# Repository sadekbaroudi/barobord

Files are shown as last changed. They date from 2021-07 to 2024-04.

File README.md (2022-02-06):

# Pronunciation

Bar-oh-board

# Support me!

I have spent a lot of time and money designing prototypes, testing, developing, etc. Any contributions would be greatly appreciated!

If you don't want to, or can't afford to support me, please send me a message to let me know you've built one, along with pictures. Also, feel free to submit a pull request with pictures into this repository. I'd be happy to showcase your build.

Reddit: /u/sadekbaroudi
Discord: sadekbaroudi#1258



# Overview

This is a split monoblock keyboard with 40 keys, a 25% typing angle, and other goodies. Feel free to use for personal use, but any selling or reselling of this is prohibited without explicit consent.

There are three versions of this board. I have personally fabricated and tested the mx and the choc versions. I have not tested the byo-mcu version, but it's the same wiring as the mx version (and much simpler). It should work fine.

See the build guide, descriptions of the three versions, and BOM for all three here:
https://github.com/sadekbaroudi/barobord/blob/master/BUILDGUIDE.md

# Do you want to test the layout?

Print the file below on a sheet of paper. Test it out!

[Layout tester](layout-tester.pdf)

# Firmware

barobord supports [vial](https://get.vial.today/)! Download it, build and flash the firmware, and vial will allow you to configure it. If you don't want to learn how to flash firmware, I have prebuilt some that you can find here:
[Prepared firmware](https://github.com/sadekbaroudi/barobord/tree/master/firmware)

If you want to build the firmware yourself, you can access it here for the integrated atmega32u4 version:
[Barobord QMK firmware](https://github.com/sadekbaroudi/vial-qmk/tree/vial/keyboards/fingerpunch/barobord)

Or here for the byo-mcu version:
[Barobord byo-mcu QMK firmware](https://github.com/sadekbaroudi/vial-qmk/tree/vial/keyboards/fingerpunch/barobord_byomcu)

# Images

## v1-mx

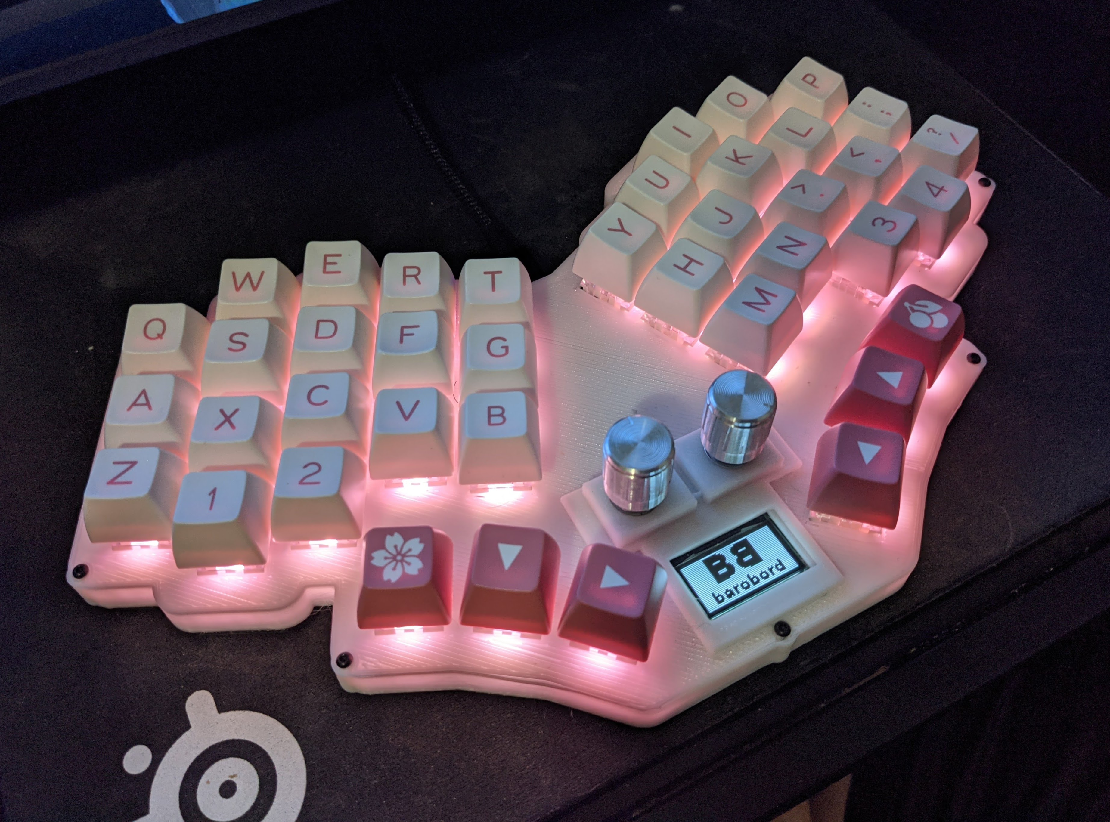
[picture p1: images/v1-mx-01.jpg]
v1mx01


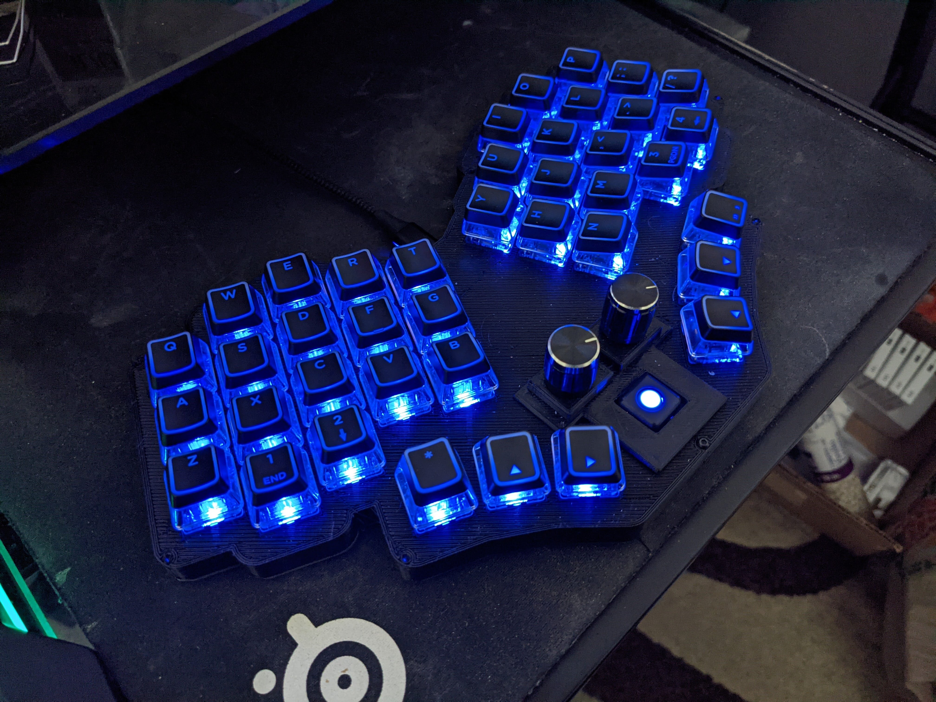
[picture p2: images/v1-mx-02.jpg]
v1mx02


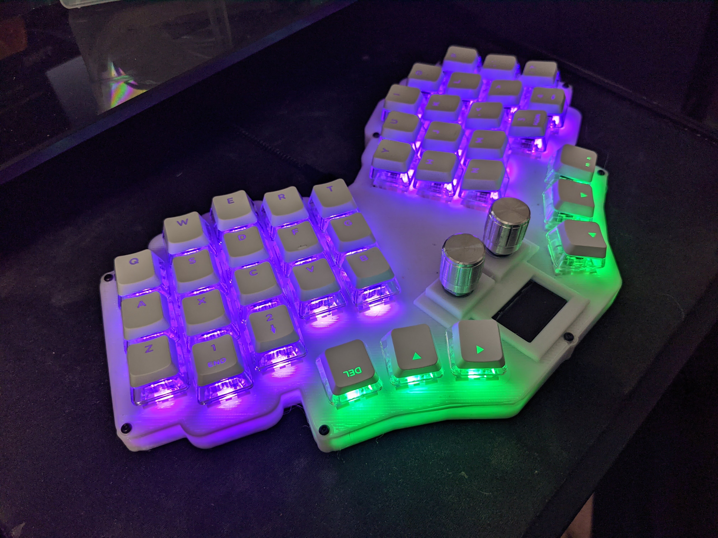
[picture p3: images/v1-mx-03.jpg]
v1mx03


## v1-choc

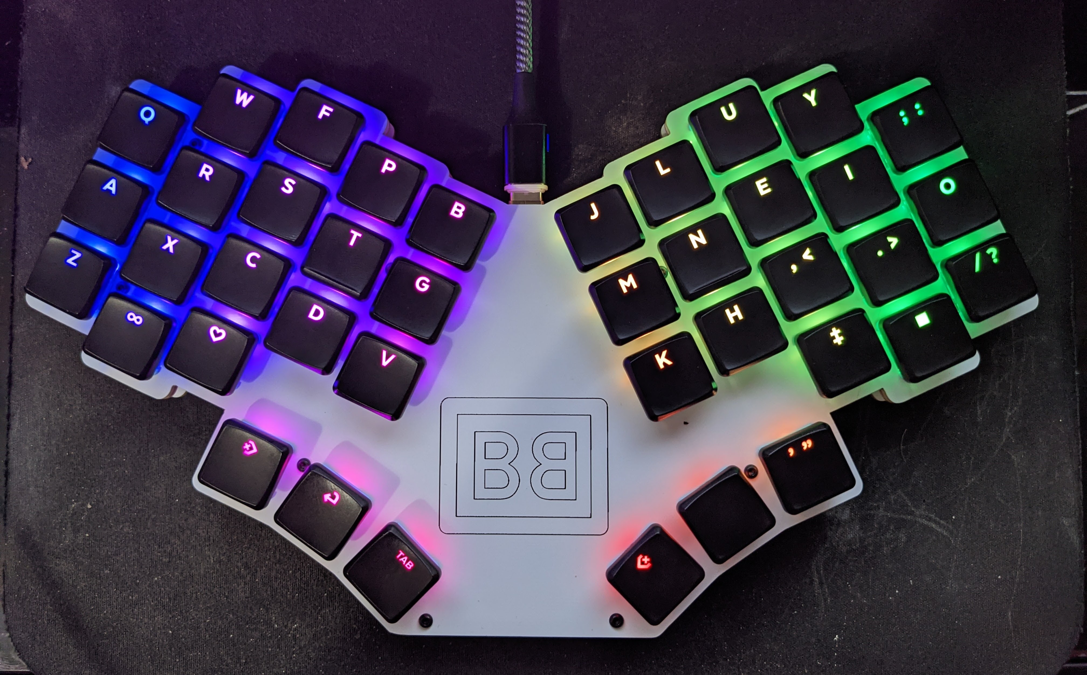
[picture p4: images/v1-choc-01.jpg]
v1choc01


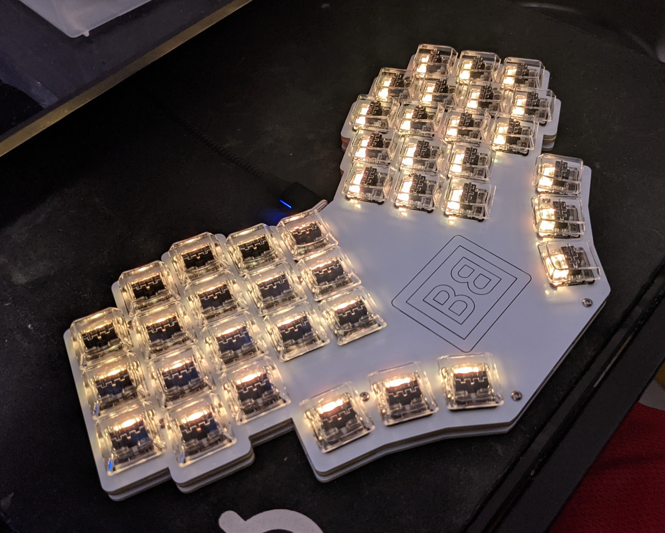
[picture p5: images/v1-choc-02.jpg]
v1choc02


## Prototype

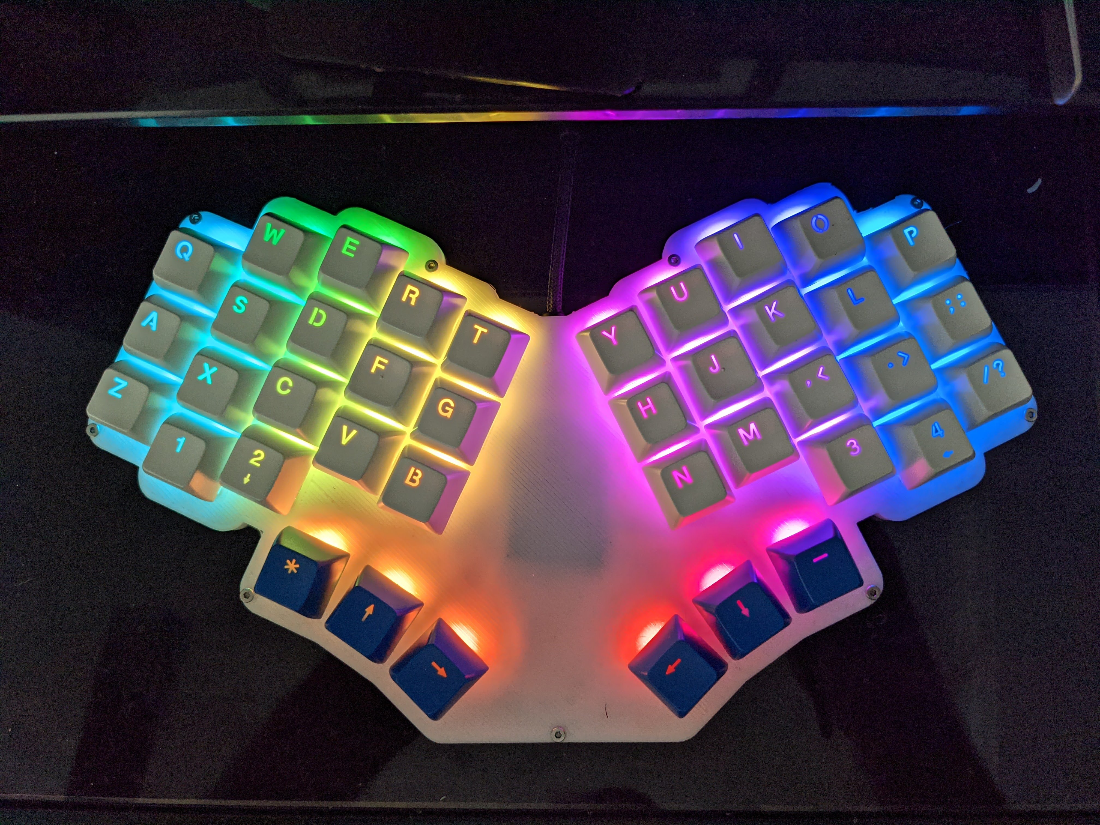
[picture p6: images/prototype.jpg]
proto1


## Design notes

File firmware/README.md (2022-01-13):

# Firmware

Depending on the features on your keyboard, download the appropriate firmware (.hex file) from this directory and flash it onto your keyboard.

The filename indicates the features you have enabled on the board. Note that these are not the only possible versions, see the link below (to my vial-qmk repo) to build your own firmware.

If you are using the embedded atmega32u4 version
* fingerpunch_barobord_rgbmatrix_oled_ec11_vial.hex - If you are using per key leds, an OLED, and EC11 encoders
* fingerpunch_barobord_rgbmatrix_pimoroni_ec11_vial.hex - If you are using per key leds, a pimoroni trackball, and EC11 encoders
* fingerpunch_barobord_rgbmatrix_vial.hex - If you are only using per key leds

If you are using the byo-mcu board:
* fingerpunch_barobord_byomcu_rgblight_vial.hex - per key leds only, and you want rgb light instead of rgb matrix
* fingerpunch_barobord_byomcu_rgbmatrix_oled_ec11_vial.hex - per key leds, oled and/or ec11 encoders
* fingerpunch_barobord_byomcu_rgbmatrix_pimoroni_ec11_vial.hex - per key leds, pimoroni and/or ec11 encoders
* fingerpunch_barobord_byomcu_rgbmatrix_vial.hex - per key leds only

Once you have done that, make sure you have [Vial](https://get.vial.today/) installed. Run it and configure it as you like!

If you want to change the firmware, the original source can be found here: [atmega32u4 embedded](https://github.com/sadekbaroudi/vial-qmk/tree/vial/keyboards/fingerpunch/barobord) or [byo-mcu version](https://github.com/sadekbaroudi/vial-qmk/tree/vial/keyboards/fingerpunch/barobord_byomcu)

I also added some user keycodes, some of which are already enabled on the default layout (currently in the Raise layer):
* User 0: Next sentence - This keycode will place a period, followed by a space, and then it will auto-capitalize the next letter you type. This is great when typing, as you only have to use one key press to start the next sentence
* User 1: Caps word - This will automatically do an all caps for the next word you type, and then will go back to lowercase
* User 2: Hyphen case - This will replace spaces with hyphens. it-will-look-something-like-this-if-you-type
* User 3: Any case - This will take the next letter you type, and use it just like the previous one (User 2). For instance, if you press this key, and then press 0, this0is0what0it0will0look0like0if0you0type
* User 4: Underscore case - This is the same as User 2, but with underscore instead of hyphen 

Note: if you'd like to check out my layout, download and load sadek-layout.vil (found in this directory)

Here is what it should look like:
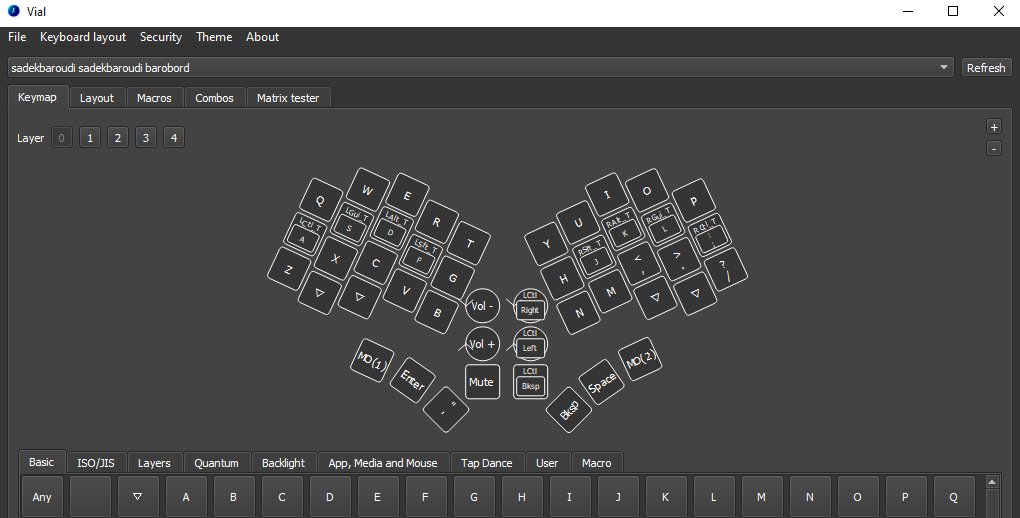
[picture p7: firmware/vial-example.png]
example


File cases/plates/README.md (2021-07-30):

./svg-dxf/*-outside-pcb.* are plates that sit outside the pcb - since there are no drill holes, this is the one that you'll likely want to use
./svg-dxf/*-size-of-pcb.* are plates that match the exact size of the pcb - you might want to use these if you want a slightly smaller keyboard, and can find a way to attach the bottom plate to the pcb without spacers or screws

I exported the svg from my fusion 360 models, then used https://convertio.co/ to convert to dxf. This resulted in the value noted below in the kicad import scale.
Note: If importing the dxf into Kicad, use Import scale 0.084650

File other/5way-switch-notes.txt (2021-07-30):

right side prongs are measured in mm from the bottom, not the top, each number is the number of mm from the previous one

pads are 1mm away from body, and should be a 1.5mm square, centered around that point...
or, make through hole version where the hole is 1mm diameter, and just outside the body (maybe 0.1mm away)

         10mm
       -------
       |     |3.3mm
10.5mm |     |2.4mm
       |     |2.0mm
       -------

29mm top, from bottom of pcb

      25mm width total

1.2mm bottom, from bottom of pcb

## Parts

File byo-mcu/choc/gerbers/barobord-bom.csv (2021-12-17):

Comment | Designator | Footprint | LCSC
SSD1306 | Brd1 | SSD1306:128x64OLED
1N4148W | D1,D2,D3,D4,D5,D6,D7,D8,D9,D10,D11,D12,D13,D14,D15,D16,D17,D18,D19,D20,D21,D22,D23,D24,D25,D26,D27,D28,D29,D30,D31,D32,D33,D34,D35,D36,D37,D38,D39,D40,D81,D82 | Diode_SMD:D_SOD-123 | C727110
SK6812MINI-E | D41,D42,D43,D44,D45,D46,D47,D48,D49,D50,D51,D52,D53,D54,D55,D56,D57,D58,D59,D60,D61,D62,D63,D64,D65,D66,D67,D68,D69,D70,D71,D72,D73,D74,D75,D76,D77,D78,D79,D80 | kicad-keyboard-parts:MX_SK6812MINI-E
Pimoroni | J1 | other_parts:pimoroni
Conn_01x03_Female | J2 | Connector_JST:JST_PH_S3B-PH-K_1x03_P2.00mm_Horizontal | C157929
10k | R4 | Resistor_SMD:R_0805_2012Metric | C17414
SW_Push | SW1,SW2,SW3,SW4,SW5,SW6,SW7,SW8,SW9,SW10,SW11,SW12,SW13,SW14,SW15,SW16,SW17,SW18,SW19,SW20,SW21,SW22,SW23,SW24,SW25,SW26,SW27,SW28,SW29,SW30,SW31,SW32,SW33,SW34,SW35,SW36,SW37,SW38,SW39,SW40 | keyswitches:Kailh_socket_PG1350
SW_Push | SW41 | random-keyboard-parts:SKQG-1155865
RotaryEncoder_Switch | SW42,SW43 | Keebio-Parts:RotaryEncoder_EC11-no-legs
EVQWGD001 | SW44,SW45 | other_parts:EVQWGD001
SW_DIP_x01 | SW46 | Button_Switch_THT:SW_CuK_OS102011MA1QN1_SPDT_Angled
Elite-C | U1 | Keebio-Parts:Elite-C
nice_nano | U2 | Keebio-Parts:nice_nano

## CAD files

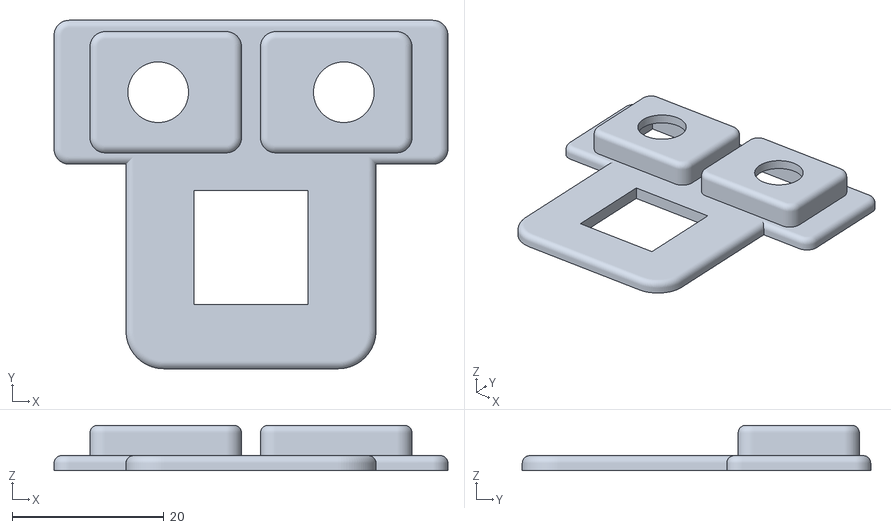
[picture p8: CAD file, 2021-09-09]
cases/covers/ec11-pim-cover.stl
52.0 x 46.0 x 6.00

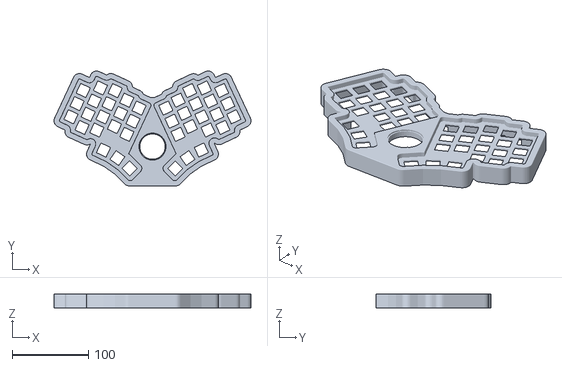
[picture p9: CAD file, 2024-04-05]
cases/hipro/body-closed-and-raised-center-cirque.stl
258.1 x 150.6 x 18.6

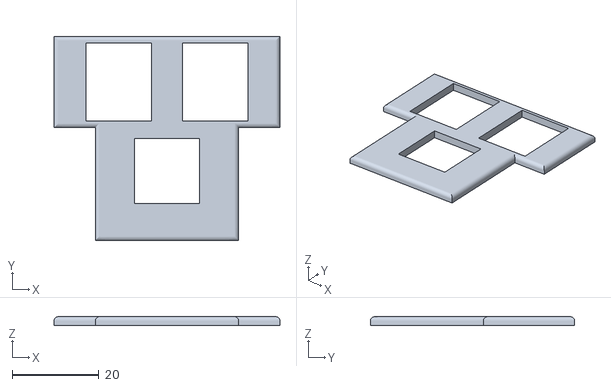
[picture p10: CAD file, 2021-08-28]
cases/pimoroni-and-encoders-type2-cover.stl
52.0 x 47.0 x 2.00

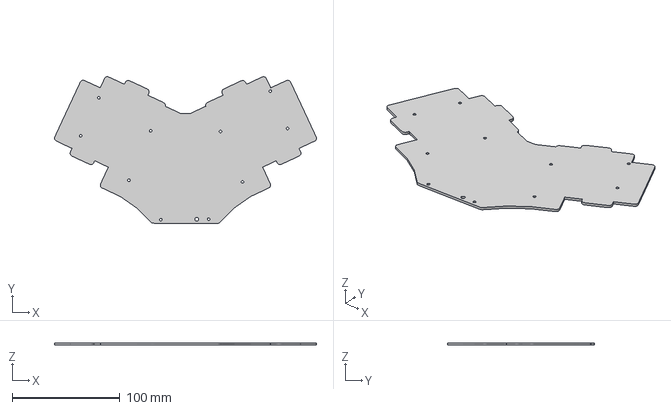
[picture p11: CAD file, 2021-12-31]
cases/plates/3D/bottom-plate-size-of-pcb.3mf
243.2 x 136.2 x 2.00 mm

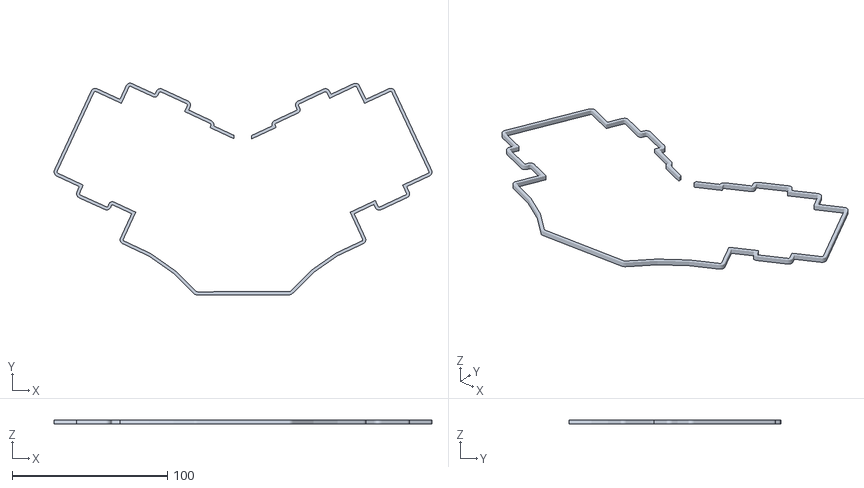
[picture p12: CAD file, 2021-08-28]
cases/plates/middle-plate-2.8mm.stl
243.2 x 136.2 x 2.80

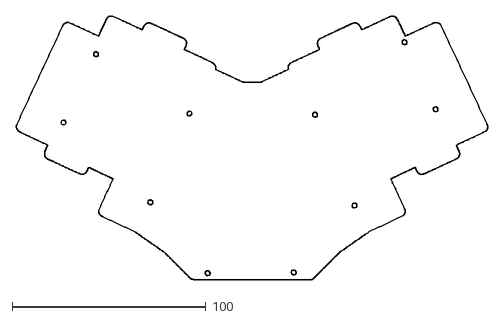
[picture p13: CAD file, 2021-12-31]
cases/plates/svg-dxf/bottom-plate-size-of-pcb.dxf
243.2 x 136.2

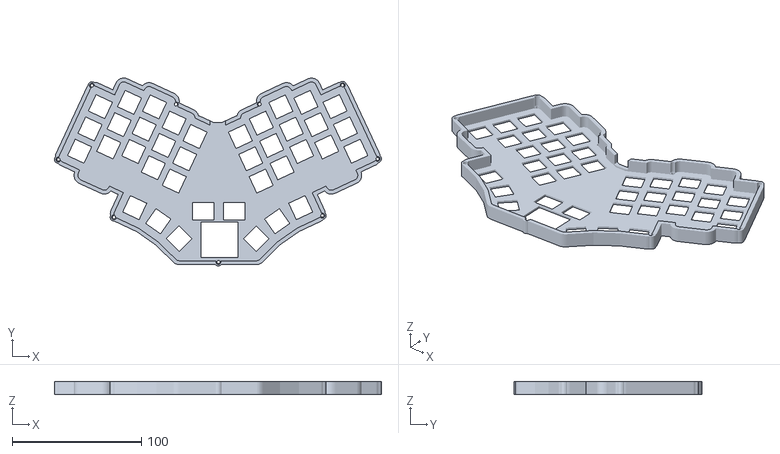
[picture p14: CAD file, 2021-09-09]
cases/sandwich/switchplate-case-36key-2rotary-and-OLED.stl
252.6 x 145.2 x 10.0

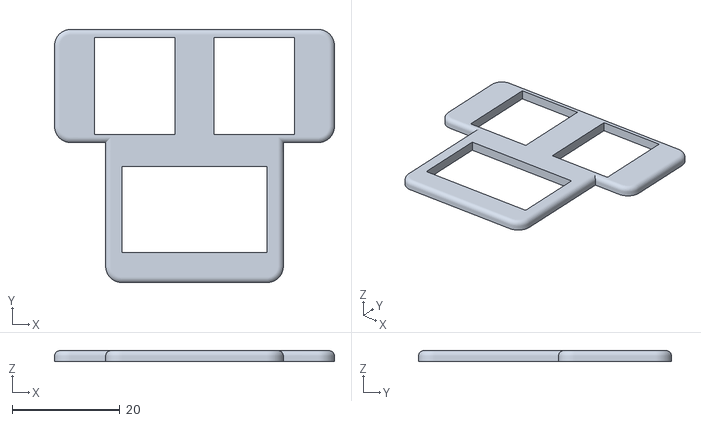
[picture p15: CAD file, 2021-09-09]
cases/covers/evqwgd001-oled-cover.stl
52.0 x 47.0 x 2.00

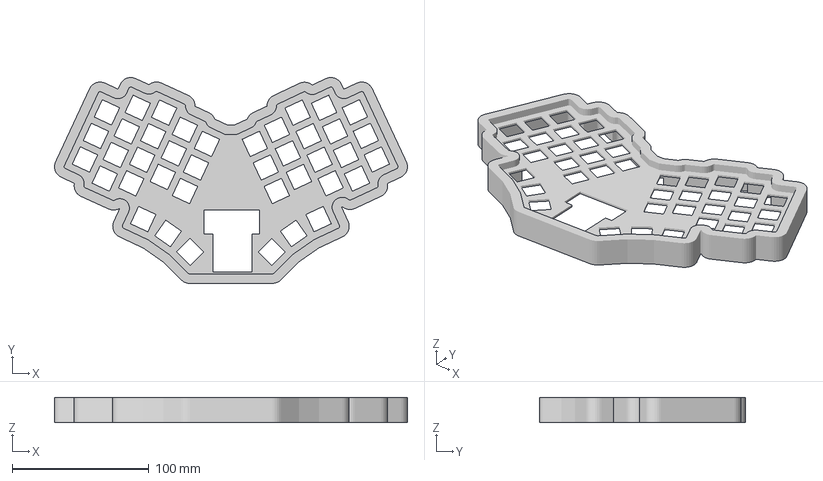
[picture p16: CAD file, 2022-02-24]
cases/hipro/body-open-center.3mf
258.1 x 150.6 x 18.6 mm

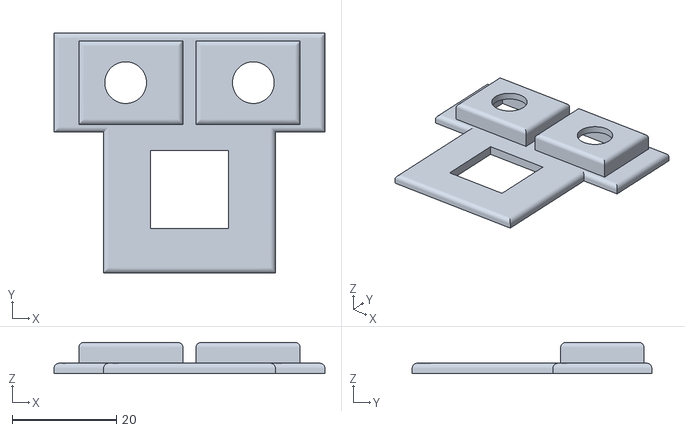
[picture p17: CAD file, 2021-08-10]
cases/pimoroni-and-encoders-cover.stl
52.0 x 46.0 x 6.00

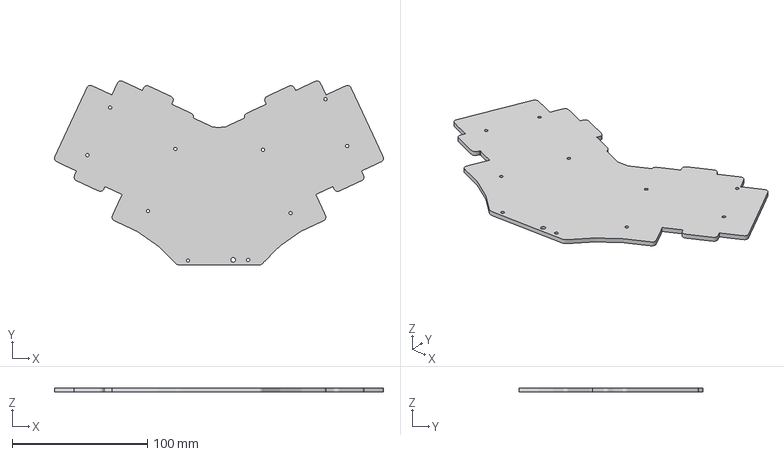
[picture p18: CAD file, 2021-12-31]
cases/plates/3D/bottom-plate-size-of-pcb-3mm.3mf
243.2 x 136.2 x 3.00 mm

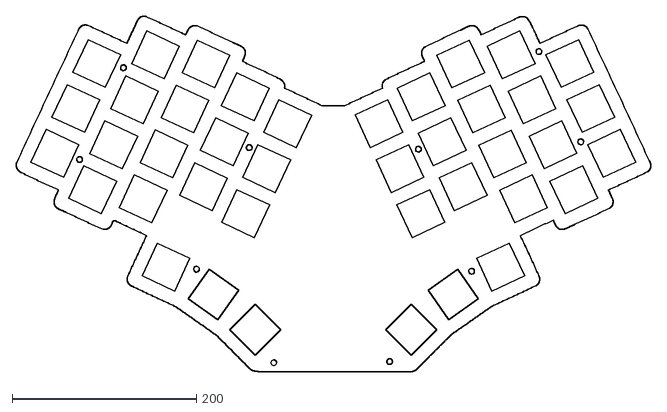
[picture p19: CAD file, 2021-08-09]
cases/plates/svg-dxf/switch-plate-size-of-pcb.dxf
689.3 x 386.1

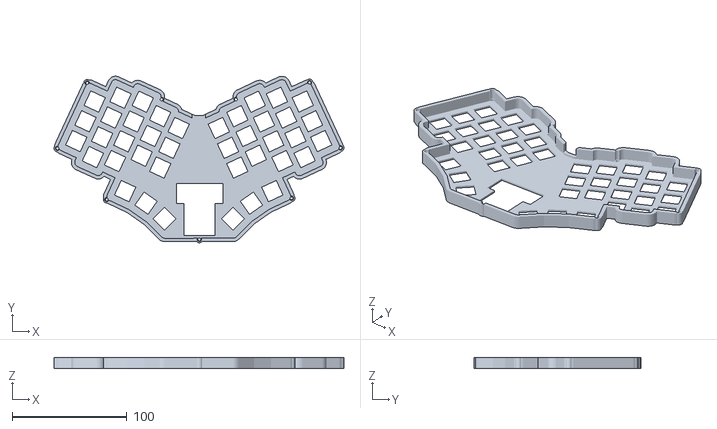
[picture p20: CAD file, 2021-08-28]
cases/sandwich/switchplate-case-2rotary-type2-and-OLED.stl
252.6 x 145.2 x 10.0

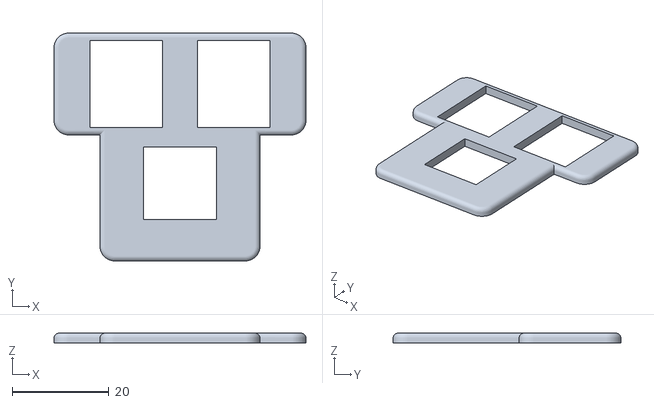
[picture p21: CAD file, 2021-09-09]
cases/covers/evqwgd001-pim-cover.stl
52.0 x 47.0 x 2.00

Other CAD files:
cases/hipro/bottom-plate.3mf
cases/OLED-and-encoders-cover.stl
cases/plates/3D/barobord-switchplate-outside-pcb.step
cases/plates/svg-dxf/switch-plate-outside-pcb.dxf
cases/covers-deprecated/OLED-and-encoders-cover.stl
cases/covers/ec11-oled-cover.stl
cases/hipro/body-closed-and-raised-center.3mf
cases/plates/3D/barobord-bottom-plate-outside-pcb.step
cases/plates/3D/barobord-bottom-plate-outside-pcb.stl
cases/plates/3D/barobord-switchplate-outside-pcb.stl
cases/plates/3D/bottom-plate-size-of-pcb-3mm.stl
cases/plates/3D/bottom-plate-size-of-pcb.stl
cases/plates/svg-dxf/bottom-plate-outside-pcb.dxf
cases/sandwich/bottom-negative-slope.stl
cases/sandwich/bottom-plate.stl
cases/sandwich/switchplate-case-2rotary-and-OLED.stl
cases/sandwich/switchplate-case-2rotary-and-pimoroni.stl
cases/sandwich/switchplate-case-2rotary-type2-and-OLED-or-pimoroni.stl
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

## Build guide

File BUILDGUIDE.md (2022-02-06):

# Introduction

There are 3 versions of the barobord available to build here. There is the byo-mcu, which supports any pro micro compatible mcu, along with the nice nano and the elite-c.

Note that the MX version (not the byo-mcu, but the atmega32u4) supports per key LED AND underglow. You have a few different configuration options:
* Per key LED only - ignore the underglow LEDs and just solder the SK6812 mini-e LEDs
* Per key LED and underglow - solder the 40 SK6812 mini-e LEDs and the WS2812B LEDs
* Underglow only - solder the 10 WS2812B LEDs and make sure you solder the jumper on the top of the board. It is just to the left of the atmega32u4

# byo-mcu (bring your own MCU)

IMPORTANT: If using this, you can only use the rotary encoders with a nice nano or elite-c compatible controller. You can use the OLED and pimoroni trackball no matter which mcu you choose.

For this pcb, here are the components you will need:

| Component | Quantity | Link |
| --- | --- | --- |
| MCU (Pro Micro compatible, Elite-c compatible, or nice!nano compatible | 1 | Google it, they're everywhere |
| SMD Diodes 0805 | 42 | https://www.lcsc.com/product-detail/Switching-Diode_TWGMC-1N4148W_C727110.html |
| SMD 10k resistor | 1 | https://www.lcsc.com/product-detail/Chip-Resistor-Surface-Mount_UNI-ROYAL-Uniroyal-Elec-0805W8F1002T5E_C17414.html |
| Kailh hotswap sockets | 40 | https://www.adafruit.com/product/4958 |
| M2 8mm standoffs | 9 | https://flashquark.com/product/m2-standoffs-8mm-20-pack/ |
| M2 4-5mm screws (NOTE: if building a choc board, use wafer head screws so they don't interfere with the choc keycaps) | 18 | https://www.amazon.com/uxcell-0-4mm-Stainless-Socket-DIN912/dp/B01M5DVE9R or https://www.metricscrews.us/index.php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 |
| SK6812 mini-e LED (optional) | 40 | https://www.adafruit.com/product/4960 |
| EC11 Rotary encoder (optional) | 2 | https://www.adafruit.com/product/377 |
| evqwgd001 Rotary encoder (optional) | 2 | https://grabcad.com/library/encoder-panasonic-evqwgd001-1 |
| 128x64 4 pin OLED (optional)  | 1 | https://www.amazon.com/DIYmall-Serial-128x64-Display-Arduino/dp/B00O2KDQBE |
| Pimoroni trackball (optional) | 1 | https://shop.pimoroni.com/products/trackball-breakout |
| JST connector, S2B-PH-K-S LF SN (optional, nice nano only) | 1 | https://www.digikey.com/en/products/detail/jst-sales-america-inc/S2B-PH-K-S-LF-SN/926626 |
| OS102011MA1QN1 on off switch (optional, nice nano only) | 1 | https://www.digikey.com/en/products/detail/c-k/OS102011MA1QN1/1981430 |

# mx and choc

These use the atmega32u4, so you'll need more components, and you will likely want to do SMT assembly. Instead of listing the components, I will point you to the following files
* https://github.com/sadekbaroudi/barobord/blob/master/mx/gerbers/barobord-bom.csv
* https://github.com/sadekbaroudi/barobord/blob/master/choc/gerbers/barobord-bom.csv

Go to the last column (LCSC), go to https://www.lcsc.com/ and search for that part number. That is the component you need.

In addition to those, you'll need:

## mx

| Component | Quantity | Link |
| --- | --- | --- |
| M2 8mm standoffs (for sandwich case) | 9 | https://flashquark.com/product/m2-standoffs-8mm-20-pack/ |
| M2 4-5mm screws (for sandwich case) | 18 | https://www.amazon.com/uxcell-0-4mm-Stainless-Socket-DIN912/dp/B01M5DVE9R |
| SK6812 mini-e LED (optional) | 40 | https://www.adafruit.com/product/4960 |
| WS2812B LED (optional) | 10 | https://www.adafruit.com/product/3094 |
| EC11 Rotary encoder (optional) | 2 | https://www.adafruit.com/product/377 |
| evqwgd001 Rotary encoder (optional) | 2 | https://grabcad.com/library/encoder-panasonic-evqwgd001-1 |
| 128x64 4 pin OLED (optional)  | 1 | https://www.amazon.com/DIYmall-Serial-128x64-Display-Arduino/dp/B00O2KDQBE |
| Pimoroni trackball (optional) | 1 | https://shop.pimoroni.com/products/trackball-breakout |

## choc

For the choc case, you can fabricate the top and bottom plates using the gerbers found here:
* https://github.com/sadekbaroudi/barobord/tree/master/cases/plates/kicad/choc

| Component | Quantity | Link |
| --- | --- | --- |
| M2 3mm standoffs (for plate style case) | 9 | Google it |
| M2 10mm screws (for plate style case) | 9 | Google it |
| M2 hex nuts (for plate style case) | 9 | Google it |
| SK6812 mini-e LED (optional) | 40 | https://www.adafruit.com/product/4960 |
| EC11 Rotary encoder (optional) | 2 | https://www.adafruit.com/product/377 |
| evqwgd001 Rotary encoder (optional) | 2 | https://grabcad.com/library/encoder-panasonic-evqwgd001-1 |
| 128x64 4 pin OLED (optional)  | 1 | https://www.amazon.com/DIYmall-Serial-128x64-Display-Arduino/dp/B00O2KDQBE |
| Pimoroni trackball (optional) | 1 | https://shop.pimoroni.com/products/trackball-breakout |

# Building

Building these is very straight forward. Solder all the components per the footprints on the board. There is no particular recommendation on how you go about doing it.

For the case, you have options depending on the board:
* https://github.com/sadekbaroudi/barobord/tree/master/cases/plates/kicad/choc (fr4, choc only)
* https://github.com/sadekbaroudi/barobord/tree/master/cases/sandwich (3d printed, any version, recommended for mx and byo-mcu)
* https://github.com/sadekbaroudi/barobord/tree/master/cases/plates/kicad/either (fr4, any version, but if you are building a choc, highly recommend the first one over this)

For the 3d printed case, you can do any combination of a switchplate and a bottom plate. The only exception is that if you use the negative switchplate , you need to use the negative bottom plate. Otherwise, use the appropriate switchplate depending on what optional components you decidede to use. 

Also, If you add rotary encoders and oled or pimoroni trackball, there are a few nice covers you can 3d print and put on top for a cleaner look. This is optional, but recommended as it looks much better. See the stls directly in this folder:
* https://github.com/sadekbaroudi/barobord/tree/master/cases/covers

Note: The fr4 plates do not support rotary encoders, OLED, or pimoroni trackball. If you want to use those, you'll have to use the stls and 3d print, or you will need to design your own fr4 plates.

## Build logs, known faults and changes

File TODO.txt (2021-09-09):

My todo list for new features:
* Add support for kicad top plate to include openings for rotary encoders and oled / pimoroni trackball
* Add break off number row and 6th columns on left and right for additional side keys
* (complete for MX version, not for byo-mcu or choc versions) Add underglow support. When adding support, extend the LEDs from the SK6812 mini-e to WS2812b, and add jumpers that route the LED pin from the atmega to the underglow directly so that you have the option of using underglow only
* Redo all the mounting holes so that they are the same positions on all versions of the barobord
* Can I add support for the atmega32u4-mu as well as the au? If I can support both, would be nice, gives flexibility during fabrication to use either

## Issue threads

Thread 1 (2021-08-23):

Build Guide

rafaeldelboni, 2021-08-23:
Hey hello, thanks for your work in this, the keyboard looks amazing and I'm planning to build a barobord (MX) myself and I have some questions :)

- Do you have a BOM (Bill of Materials)?
- I can use the Gerber.zip in the MX file or do you recommend generating it again?
- Do you have a top switchplate variation with the cuts for the encoders and the OLED?

sadekbaroudi, 2021-09-01:
Hi @rafaeldelboni - I'm glad you'll be building this! Please share pictures of your build. You can submit a pull request to put in the images directory and readme.md

* I can add a BOM for a build guide, sure. I'll keep this issue open until I do that. Note that if you use JLCPCB, I have generated the necessary BOM and POS files. You can use these files directly in the SMT assembly service ( https://github.com/sadekbaroudi/barobord/blob/master/mx/gerbers/barobord-bom.csv and https://github.com/sadekbaroudi/barobord/blob/master/mx/gerbers/barobord-bottom-pos.csv )
* I am pretty sure I updated it. I generate updated gerbers every time I make changes. But if you want to be safe, feel free to generate again.
* You can see I have stls for all variations here: https://github.com/sadekbaroudi/barobord/tree/master/cases/sandwich

sadekbaroudi, 2021-09-01:
@rafaeldelboni

Also, if you look at the last column in the bom csv link above, you'll see LSCS. You can use that part number to look up the parts on https://lcsc.com/

That will tell you all the components you need.

In addition to that, you'll just need M2 spacers (I think 8mm, maybe it's 10mm) and screws (4-6mm should be fine) to assemble the case. The rest is all in that csv.

sadekbaroudi, 2021-09-03:
Added build guide in this commit:
https://github.com/sadekbaroudi/barobord/commit/c60ef5b02c841b090c1f3999e4f607ca9856b418

rafaeldelboni, 2021-09-03:
I will start to build this soon, thanks for all your work on this.

sadekbaroudi, 2022-01-09:
@rafaeldelboni - did you ever build this? Would love to see pictures!

rafaeldelboni, 2022-01-10:
Hey @sadekbaroudi, I will build one this year haha, thanks for the reminder, I will start to get the parts.
My Torn is still working beautifully, but I want to try something new :)
Hope you doing great :D

sadekbaroudi, 2022-01-10:
@rafaeldelboni Nice! Enjoy! As always, let me know if you have any questions.

Closed 2021-09-03.

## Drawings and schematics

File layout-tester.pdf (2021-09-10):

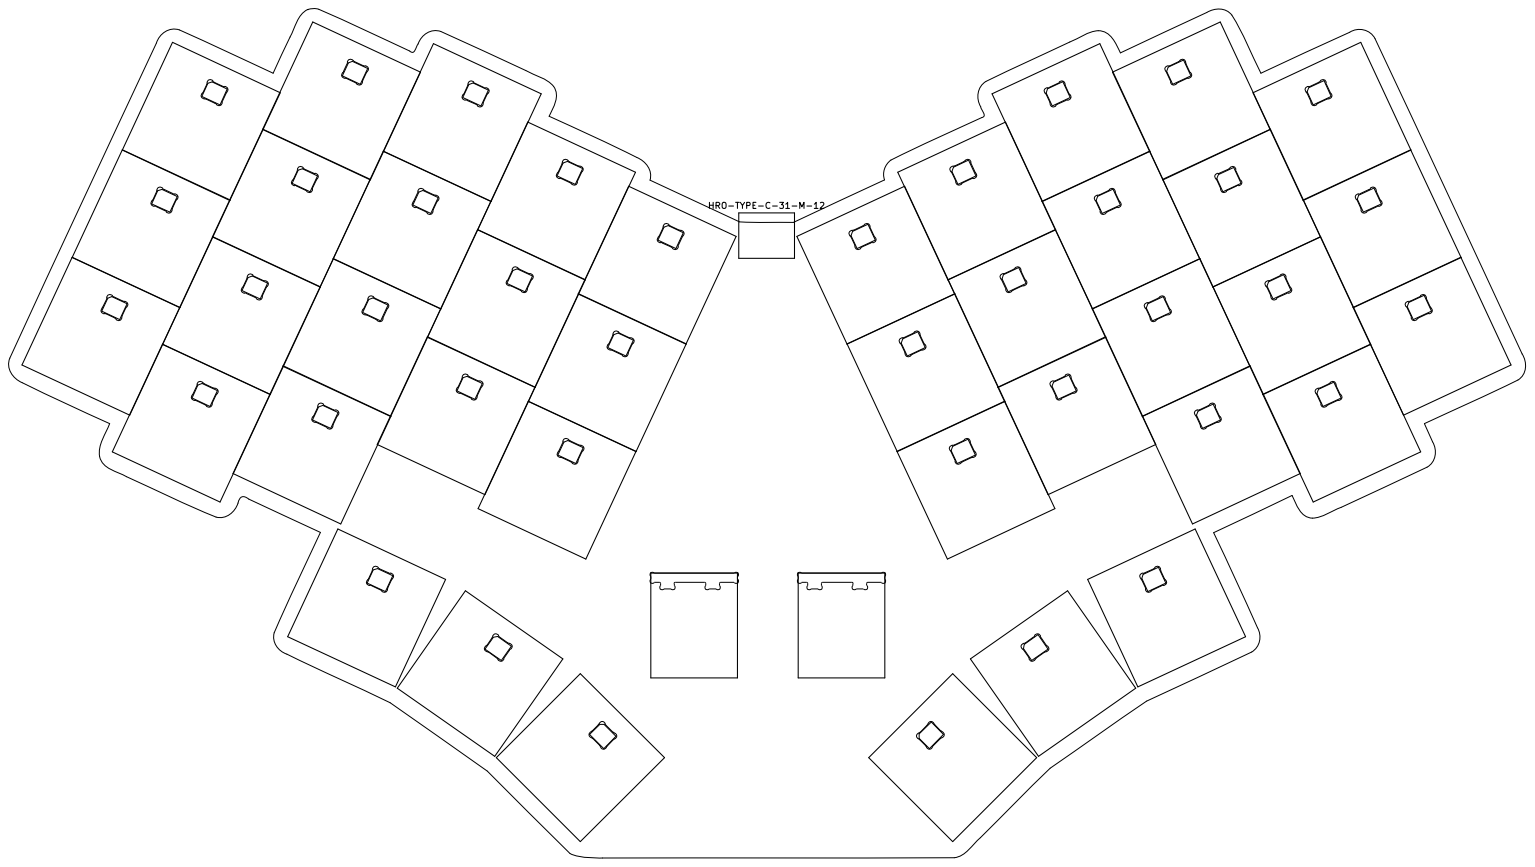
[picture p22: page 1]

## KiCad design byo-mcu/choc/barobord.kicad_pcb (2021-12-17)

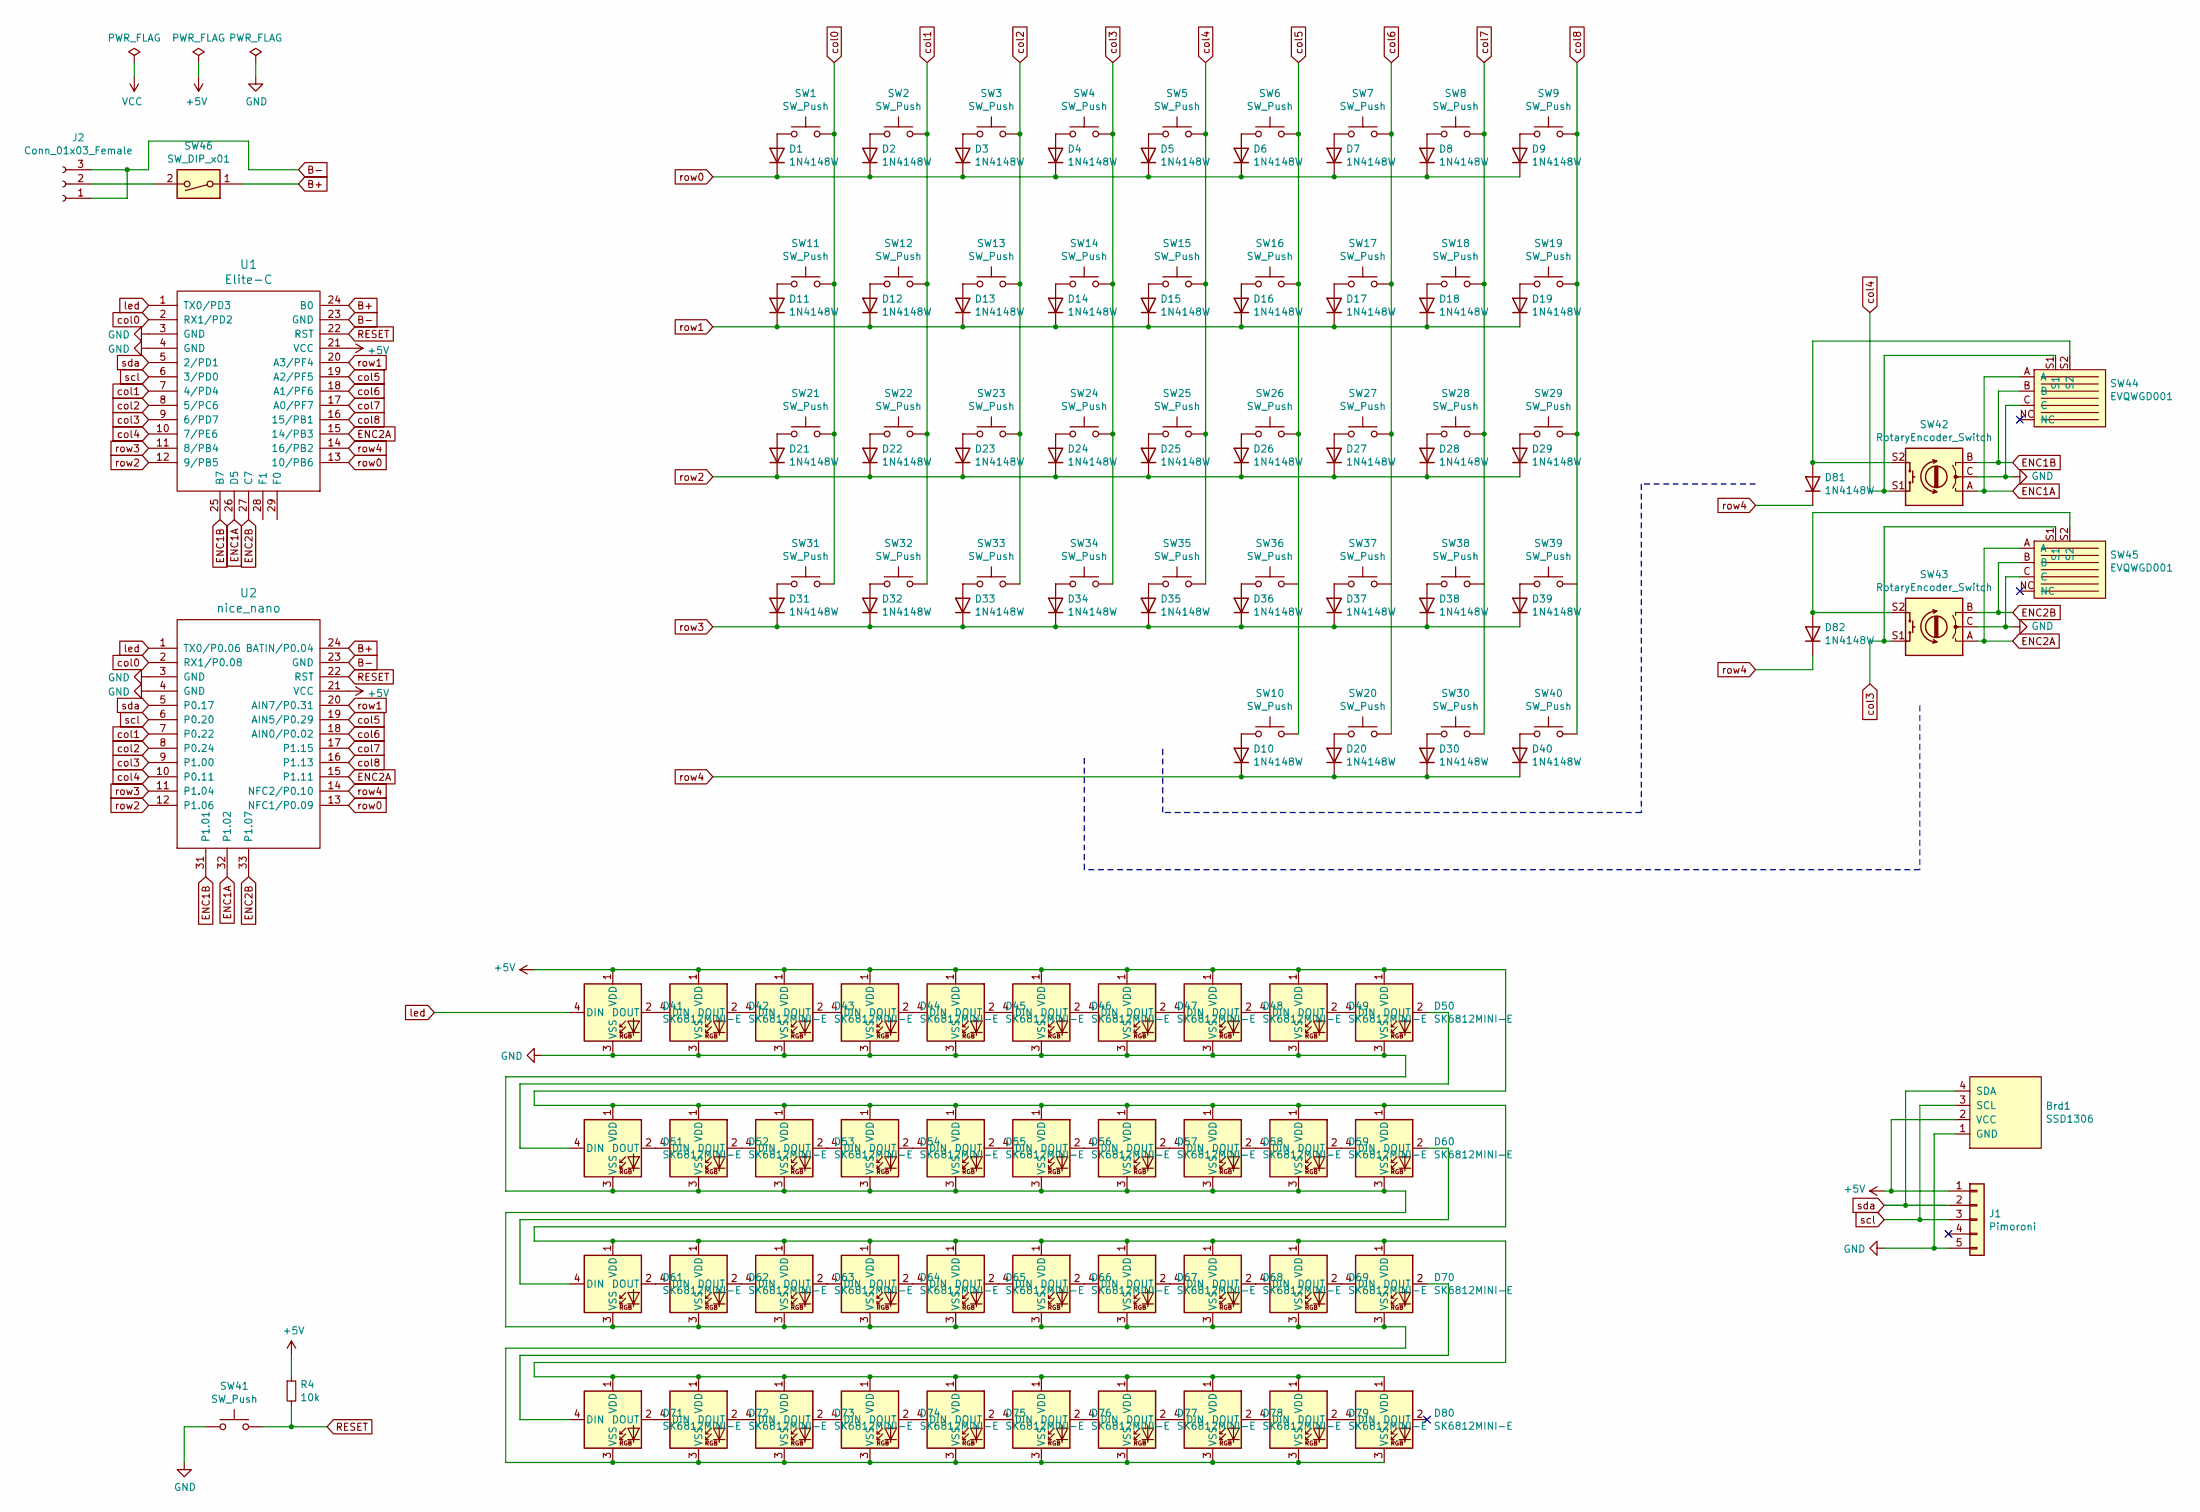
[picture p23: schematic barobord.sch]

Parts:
Brd1: SSD1306; 128x64OLED
D1, D2, D3, D4, D5, D6, D7, D8, D9, D10, D11, D12, D13, D14, D15, D16, D17, D18, D19, D20, D21, D22, D23, D24, D25, D26, D27, D28, D29, D30, D31, D32, D33, D34, D35, D36, D37, D38, D39, D40, D81, D82: 1N4148W; D_SOD-123; LCSC C727110
D41, D42, D43, D44, D45, D46, D47, D48, D49, D50, D51, D52, D53, D54, D55, D56, D57, D58, D59, D60, D61, D62, D63, D64, D65, D66, D67, D68, D69, D70, D71, D72, D73, D74, D75, D76, D77, D78, D79, D80: SK6812MINI-E; MX_SK6812MINI-E
J1: Pimoroni; pimoroni
J2: Conn_01x03_Female; JST_PH_S3B-PH-K_1x03_P2.00mm_Horizontal; LCSC C157929
R4: 10k; R_0805_2012Metric; LCSC C17414
SW1, SW2, SW3, SW4, SW5, SW6, SW7, SW8, SW9, SW10, SW11, SW12, SW13, SW14, SW15, SW16, SW17, SW18, SW19, SW20, SW21, SW22, SW23, SW24, SW25, SW26, SW27, SW28, SW29, SW30, SW31, SW32, SW33, SW34, SW35, SW36, SW37, SW38, SW39, SW40: SW_Push; Kailh_socket_PG1350
SW41: SW_Push; SKQG-1155865
SW42, SW43: RotaryEncoder_Switch; RotaryEncoder_EC11-no-legs
SW44, SW45: EVQWGD001
SW46: SW_DIP_x01; SW_CuK_OS102011MA1QN1_SPDT_Angled
U1: Elite-C
U2: nice_nano

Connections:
+5V: Brd1.2 (VCC), D41.1 (VDD), D42.1 (VDD), D43.1 (VDD), D44.1 (VDD), D45.1 (VDD), D46.1 (VDD), D47.1 (VDD), D48.1 (VDD), D49.1 (VDD), D50.1 (VDD), D51.1 (VDD), D52.1 (VDD), D53.1 (VDD), D54.1 (VDD), D55.1 (VDD), D56.1 (VDD), D57.1 (VDD), D58.1 (VDD), D59.1 (VDD), D60.1 (VDD), D61.1 (VDD), D62.1 (VDD), D63.1 (VDD), D64.1 (VDD), D65.1 (VDD), D66.1 (VDD), D67.1 (VDD), D68.1 (VDD), D69.1 (VDD), D70.1 (VDD), D71.1 (VDD), D72.1 (VDD), D73.1 (VDD), D74.1 (VDD), D75.1 (VDD), D76.1 (VDD), D77.1 (VDD), D78.1 (VDD), D79.1 (VDD), D80.1 (VDD), J1.1, R4.1, U1.21 (VCC), U2.21 (VCC)
B+: SW46.1, U1.24 (B0), U2.24 (BATIN/P0.04)
B-: J2.1, J2.3, U1.23 (GND), U2.23 (GND)
ENC1A: SW42.A, SW44.A, U1.26 (D5), U2.32 (P1.02)
ENC1B: SW42.B, SW44.B, U1.25 (B7), U2.31 (P1.01)
ENC2A: SW43.A, SW45.A, U1.15 (14/PB3), U2.15 (P1.11)
ENC2B: SW43.B, SW45.B, U1.27 (C7), U2.33 (P1.07)
GND: Brd1.1 (GND), D41.3 (VSS), D42.3 (VSS), D43.3 (VSS), D44.3 (VSS), D45.3 (VSS), D46.3 (VSS), D47.3 (VSS), D48.3 (VSS), D49.3 (VSS), D50.3 (VSS), D51.3 (VSS), D52.3 (VSS), D53.3 (VSS), D54.3 (VSS), D55.3 (VSS), D56.3 (VSS), D57.3 (VSS), D58.3 (VSS), D59.3 (VSS), D60.3 (VSS), D61.3 (VSS), D62.3 (VSS), D63.3 (VSS), D64.3 (VSS), D65.3 (VSS), D66.3 (VSS), D67.3 (VSS), D68.3 (VSS), D69.3 (VSS), D70.3 (VSS), D71.3 (VSS), D72.3 (VSS), D73.3 (VSS), D74.3 (VSS), D75.3 (VSS), D76.3 (VSS), D77.3 (VSS), D78.3 (VSS), D79.3 (VSS), D80.3 (VSS), J1.5, SW41.1, SW42.C, SW43.C, SW44.C, SW45.C, U1.3 (GND), U1.4 (GND), U2.3 (GND), U2.4 (GND)
unnamed: D1.2 (A), SW1.1
unnamed: D2.2 (A), SW2.1
unnamed: D3.2 (A), SW3.1
unnamed: D4.2 (A), SW4.1
unnamed: D5.2 (A), SW5.1
unnamed: D6.2 (A), SW6.1
unnamed: D7.2 (A), SW7.1
unnamed: D8.2 (A), SW8.1
unnamed: D9.2 (A), SW9.1
unnamed: D10.2 (A), SW10.1
unnamed: D11.2 (A), SW11.1
unnamed: D12.2 (A), SW12.1
unnamed: D13.2 (A), SW13.1
unnamed: D14.2 (A), SW14.1
unnamed: D15.2 (A), SW15.1
unnamed: D16.2 (A), SW16.1
unnamed: D17.2 (A), SW17.1
unnamed: D18.2 (A), SW18.1
unnamed: D19.2 (A), SW19.1
unnamed: D20.2 (A), SW20.1
unnamed: D21.2 (A), SW21.1
unnamed: D22.2 (A), SW22.1
unnamed: D23.2 (A), SW23.1
unnamed: D24.2 (A), SW24.1
unnamed: D25.2 (A), SW25.1
unnamed: D26.2 (A), SW26.1
unnamed: D27.2 (A), SW27.1
unnamed: D28.2 (A), SW28.1
unnamed: D29.2 (A), SW29.1
unnamed: D30.2 (A), SW30.1
unnamed: D31.2 (A), SW31.1
unnamed: D32.2 (A), SW32.1
unnamed: D33.2 (A), SW33.1
unnamed: D34.2 (A), SW34.1
unnamed: D35.2 (A), SW35.1
unnamed: D36.2 (A), SW36.1
unnamed: D37.2 (A), SW37.1
unnamed: D38.2 (A), SW38.1
unnamed: D39.2 (A), SW39.1
unnamed: D40.2 (A), SW40.1
unnamed: D41.2 (DOUT), D42.4 (DIN)
unnamed: D42.2 (DOUT), D43.4 (DIN)
unnamed: D43.2 (DOUT), D44.4 (DIN)
unnamed: D44.2 (DOUT), D45.4 (DIN)
unnamed: D45.2 (DOUT), D46.4 (DIN)
unnamed: D46.2 (DOUT), D47.4 (DIN)
unnamed: D47.2 (DOUT), D48.4 (DIN)
unnamed: D48.2 (DOUT), D49.4 (DIN)
unnamed: D49.2 (DOUT), D50.4 (DIN)
unnamed: D50.2 (DOUT), D51.4 (DIN)
unnamed: D51.2 (DOUT), D52.4 (DIN)
unnamed: D52.2 (DOUT), D53.4 (DIN)
unnamed: D53.2 (DOUT), D54.4 (DIN)
unnamed: D54.2 (DOUT), D55.4 (DIN)
unnamed: D55.2 (DOUT), D56.4 (DIN)
unnamed: D56.2 (DOUT), D57.4 (DIN)
unnamed: D57.2 (DOUT), D58.4 (DIN)
unnamed: D58.2 (DOUT), D59.4 (DIN)
unnamed: D59.2 (DOUT), D60.4 (DIN)
unnamed: D60.2 (DOUT), D61.4 (DIN)
unnamed: D61.2 (DOUT), D62.4 (DIN)
unnamed: D62.2 (DOUT), D63.4 (DIN)
unnamed: D63.2 (DOUT), D64.4 (DIN)
unnamed: D64.2 (DOUT), D65.4 (DIN)
unnamed: D65.2 (DOUT), D66.4 (DIN)
unnamed: D66.2 (DOUT), D67.4 (DIN)
unnamed: D67.2 (DOUT), D68.4 (DIN)
unnamed: D68.2 (DOUT), D69.4 (DIN)
unnamed: D69.2 (DOUT), D70.4 (DIN)
unnamed: D70.2 (DOUT), D71.4 (DIN)
unnamed: D71.2 (DOUT), D72.4 (DIN)
unnamed: D72.2 (DOUT), D73.4 (DIN)
unnamed: D73.2 (DOUT), D74.4 (DIN)
unnamed: D74.2 (DOUT), D75.4 (DIN)
unnamed: D75.2 (DOUT), D76.4 (DIN)
unnamed: D76.2 (DOUT), D77.4 (DIN)
unnamed: D77.2 (DOUT), D78.4 (DIN)
unnamed: D78.2 (DOUT), D79.4 (DIN)
unnamed: D79.2 (DOUT), D80.4 (DIN)
unnamed: D81.2 (A), SW42.S2, SW44.S2
unnamed: D82.2 (A), SW43.S2, SW45.S2
unnamed: J2.2, SW46.2
RESET: R4.2, SW41.2, U1.22 (RST), U2.22 (RST)
col0: SW1.2, SW11.2, SW21.2, SW31.2, U1.2 (RX1/PD2), U2.2 (RX1/P0.08)
col1: SW2.2, SW12.2, SW22.2, SW32.2, U1.7 (4/PD4), U2.7 (P0.22)
col2: SW3.2, SW13.2, SW23.2, SW33.2, U1.8 (5/PC6), U2.8 (P0.24)
col3: SW4.2, SW14.2, SW24.2, SW34.2, SW43.S1, SW45.S1, U1.9 (6/PD7), U2.9 (P1.00)
col4: SW5.2, SW15.2, SW25.2, SW35.2, SW42.S1, SW44.S1, U1.10 (7/PE6), U2.10 (P0.11)
col5: SW6.2, SW10.2, SW16.2, SW26.2, SW36.2, U1.19 (A2/PF5), U2.19 (AIN5/P0.29)
col6: SW7.2, SW17.2, SW20.2, SW27.2, SW37.2, U1.18 (A1/PF6), U2.18 (AIN0/P0.02)
col7: SW8.2, SW18.2, SW28.2, SW30.2, SW38.2, U1.17 (A0/PF7), U2.17 (P1.15)
col8: SW9.2, SW19.2, SW29.2, SW39.2, SW40.2, U1.16 (15/PB1), U2.16 (P1.13)
led: D41.4 (DIN), U1.1 (TX0/PD3), U2.1 (TX0/P0.06)
row0: D1.1 (K), D2.1 (K), D3.1 (K), D4.1 (K), D5.1 (K), D6.1 (K), D7.1 (K), D8.1 (K), D9.1 (K), U1.13 (10/PB6), U2.13 (NFC1/P0.09)
row1: D11.1 (K), D12.1 (K), D13.1 (K), D14.1 (K), D15.1 (K), D16.1 (K), D17.1 (K), D18.1 (K), D19.1 (K), U1.20 (A3/PF4), U2.20 (AIN7/P0.31)
row2: D21.1 (K), D22.1 (K), D23.1 (K), D24.1 (K), D25.1 (K), D26.1 (K), D27.1 (K), D28.1 (K), D29.1 (K), U1.12 (9/PB5), U2.12 (P1.06)
row3: D31.1 (K), D32.1 (K), D33.1 (K), D34.1 (K), D35.1 (K), D36.1 (K), D37.1 (K), D38.1 (K), D39.1 (K), U1.11 (8/PB4), U2.11 (P1.04)
row4: D10.1 (K), D20.1 (K), D30.1 (K), D40.1 (K), D81.1 (K), D82.1 (K), U1.14 (16/PB2), U2.14 (NFC2/P0.10)
scl: Brd1.3 (SCL), J1.3, U1.6 (3/PD0), U2.6 (P0.20)
sda: Brd1.4 (SDA), J1.2, U1.5 (2/PD1), U2.5 (P0.17)

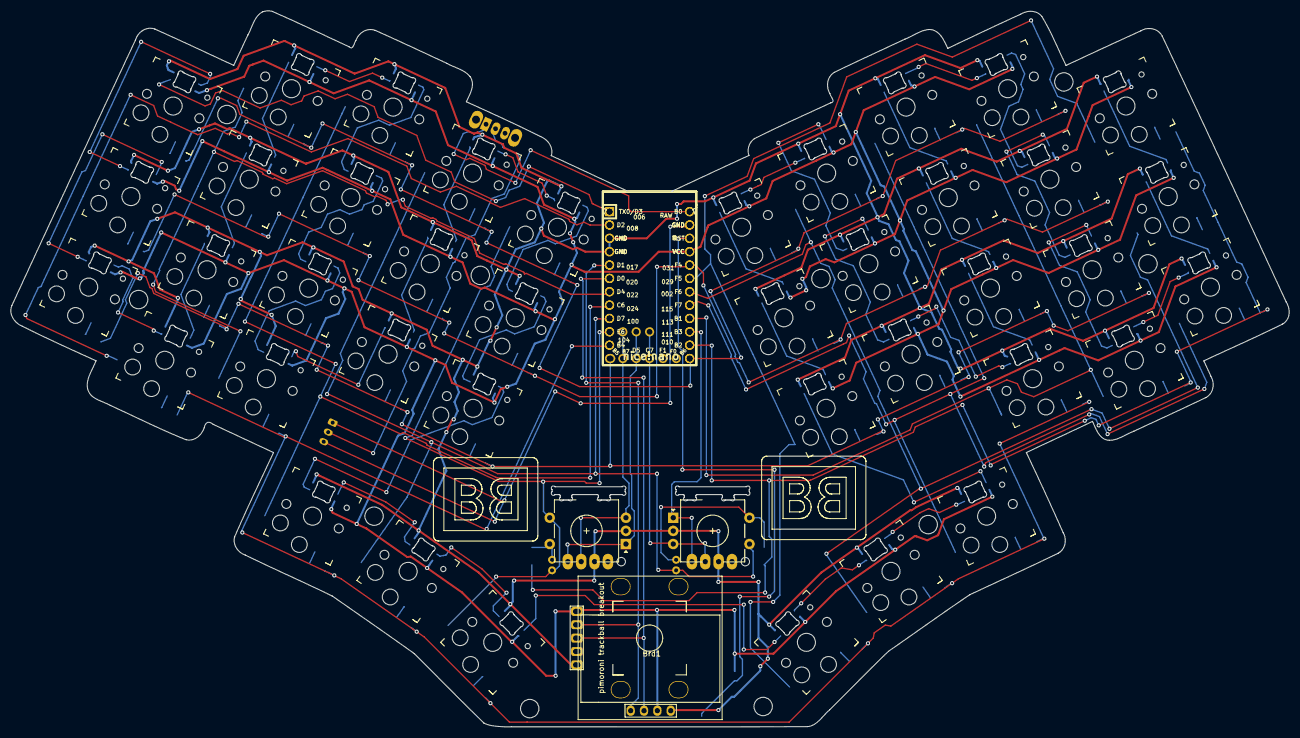
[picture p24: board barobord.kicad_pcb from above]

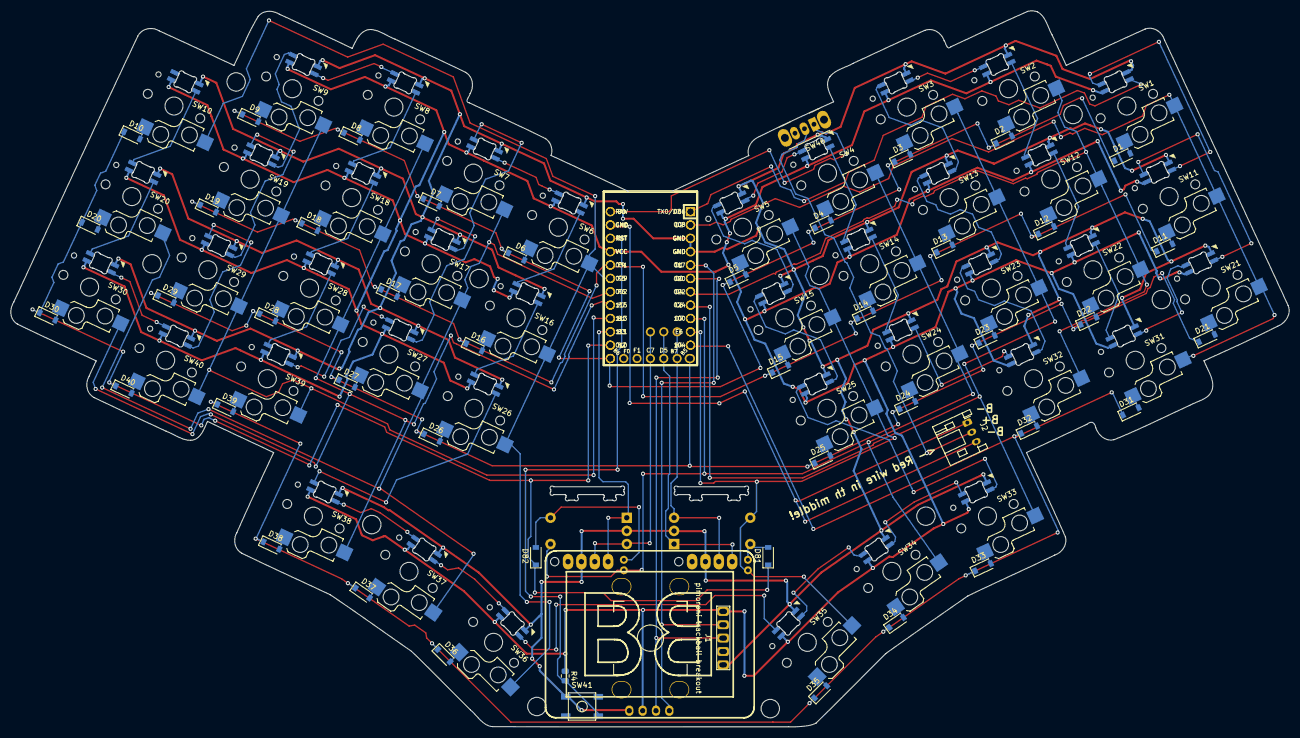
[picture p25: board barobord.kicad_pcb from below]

Board: 2 copper layers, 243.2 x 136.2 mm, 134 parts (47 on the bottom side), 108 nets.

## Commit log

2021-07-15 first commit, schematic complete, still need to wire everything
    [baroboard-pcb-outline-r14.dxf, barobord.kicad_pcb, barobord.sch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]
2021-07-15 first phase of wiring complete - mcu, usb, and rows and columns
    [barobord.kicad_pcb, barobord.sch]
2021-07-16 wiring and layout complete, will still add some cool stuff in the middle
    [barobord.kicad_pcb, barobord.sch]
2021-07-16 few fixes to the schematic and wiring
    [barobord.kicad_pcb, barobord.sch]
2021-07-16 added logo and gerbers
    [BB-logo.dxf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]
2021-07-17 added pimoroni trackball support, updated logo
    [BB-logo2.dxf, barobord.kicad_pcb, barobord.sch]
2021-07-17 Added two rotary encoders
    [barobord.kicad_pcb, barobord.sch]
2021-07-17 Added OLED support, must pick either OLED or pimoroni, as they both use SDA SCL
    [barobord.kicad_pcb, barobord.sch]
2021-07-17 Forgot to add column 10 for rotary encoder switches
    [barobord.kicad_pcb, barobord.sch]
2021-07-18 Added support for the EVQWGD001 rotary encoders
    [barobord.kicad_pcb, barobord.sch]
2021-07-18 Updated gerbers
    [barobord-B_Cu.gbr, barobord-B_Mask.gbr, barobord-B_Paste.gbr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]
2021-07-25 added choc board, updated mx board to have reversed switch footprints for LEDs on top
    [BB-logo.dxf, BB-logo2.dxf, baroboard-pcb-outline-r14.dxf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]
2021-07-25 moved base directory to mx directory
    [BB-logo.dxf, BB-logo2.dxf, baroboard-pcb-outline-r14.dxf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]
2021-07-30 added plate svgs and dxfs, OLED logo, and some notes for future changes
    [barobord-bottomplate-outside-pcb.kicad_pcb, barobord-bottomplate-size-of-pcb.kicad_pcb, barobord-switchplate-outside-pcb.kicad_pcb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]
2021-07-30 added 3d models for plate case as well
    [barobord-bottom-plate-outside-pcb.step, barobord-bottom-plate-outside-pcb.stl, barobord-bottom-plate.step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]
2021-08-01 added better case
    [switchplate-case-2rotary-and-OLED.stl, switchplate-case-2rotary-and-pimoroni.stl, switchplate-case.stl]
2021-08-02 added new negatively sloped case
    [bottom-8-percent-slope.stl]
2021-08-06 updated encoders to be a little higher, don't think I'm going to use this, but committing just in case
    [barobord-encoders-up-3mm.kicad_pcb]
2021-08-06 updating and adding cases
    [bottom-negative-slope.stl, switchplate-case-2rotary-and-OLED.stl, switchplate-negative-slope.stl]
2021-08-08 updated choc plates and added pimoroni OLED and encoder covers
    [OLED-and-encoders-cover.stl, barobord-bottomplate-size-of-pcb.kicad_pcb, barobord-switchplate-size-of-pcb.kicad_pcb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]
2021-08-08 updated bottom plate
    [bottom-plate-B_Cu.gbr, bottom-plate-B_Mask.gbr, bottom-plate-B_Paste.gbr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]
2021-08-09 get choc ready for fabrication
    [barobord-B_Cu.gbr, barobord-B_Mask.gbr, barobord-B_Paste.gbr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]
2021-08-10 Updated covers STLs to be better fit the spacing
    [OLED-and-encoders-cover.stl, pimoroni-and-encoders-cover.stl]
2021-08-28 updated images, cases, and readmes
    [BB-logo.dxf, BB-logo2.dxf, baroboard-pcb-outline-r14.dxf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]
2021-08-28 removing choc bottom plate gerbers directory
    [bottom-plate-B_Cu.gbr, bottom-plate-B_Mask.gbr, bottom-plate-B_Paste.gbr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]
2021-09-03 added an MCU agnostic pcb
    [barobord.kicad_pcb, barobord.sch]
2021-09-03 removed the version where I moved the encoders
    [barobord-encoders-up-3mm.kicad_pcb]
2021-09-03 added byo-mcu gerbers
    [barobord-B_Cu.gbr, barobord-B_Mask.gbr, barobord-B_Paste.gbr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]
2021-09-03 updated mcu footprint to show pinout for both nice nano and elite-c
    [barobord-B_Cu.gbr, barobord-B_Mask.gbr, barobord-B_Paste.gbr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]
2021-09-09 added underglow support for the MX version (not byo-mcu or choc)
    [barobord-B_Cu.gbr, barobord-B_Mask.gbr, barobord-B_Paste.gbr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]
2021-09-09 added rounded corners to covers, and added support for one more cover type
    [OLED-and-encoders-cover.stl, ec11-oled-cover.stl, ec11-pim-cover.stl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]
2021-09-09 added 36 key switchplate case for elisiano
    [switchplate-case-36key-2rotary-and-OLED.stl]
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2021-09-18 added gerbers for plates that support any barobord
    [barobord-bottomplate-outside-pcb-B_Cu.gbr, barobord-bottomplate-outside-pcb-B_Mask.gbr, barobord-bottomplate-outside-pcb-B_SilkS.gbr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]
2021-09-18 updated kicad files according to the previous commit's gerbers
    [barobord-bottomplate-outside-pcb.kicad_pcb, barobord-switchplate-outside-pcb.kicad_pcb]
2021-09-18 moved outside plates to either directory
    [barobord-bottomplate-outside-pcb.kicad_pcb, barobord-switchplate-outside-pcb.kicad_pcb]
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2021-11-13 updated byo-mcu to work
    [barobord-B_Cu.gbr, barobord-B_Mask.gbr, barobord-B_Paste.gbr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]
2021-12-09 added mounting holes for byo-mcu, and moved the on off switch to the top of the board
    [barobord-B_Cu.gbr, barobord-B_Mask.gbr, barobord-B_Paste.gbr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]
2021-12-10 added byo-mcu choc version for Apsu
    [barobord-B_Cu.gbr, barobord-B_Mask.gbr, barobord-B_Paste.gbr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]
2021-12-17 converted jst connector from 2 pin to 3 pin to help prevent people from plugging in the battery backwards, and to support both wiring configurations for batteries
    [barobord-B_Cu.gbr, barobord-B_Mask.gbr, barobord-B_Paste.gbr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]
2021-12-31 added bottom plate 3d printable files
    [bottom-plate-size-of-pcb-3mm.3mf, bottom-plate-size-of-pcb-3mm.stl, bottom-plate-size-of-pcb.3mf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]
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2022-02-24 added high profile case
    [body-closed-and-raised-center.3mf, body-open-center.3mf, bottom-plate.3mf]
2024-04-05 added cirque support for barobord high profile case
    [body-closed-and-raised-center-cirque.stl]
